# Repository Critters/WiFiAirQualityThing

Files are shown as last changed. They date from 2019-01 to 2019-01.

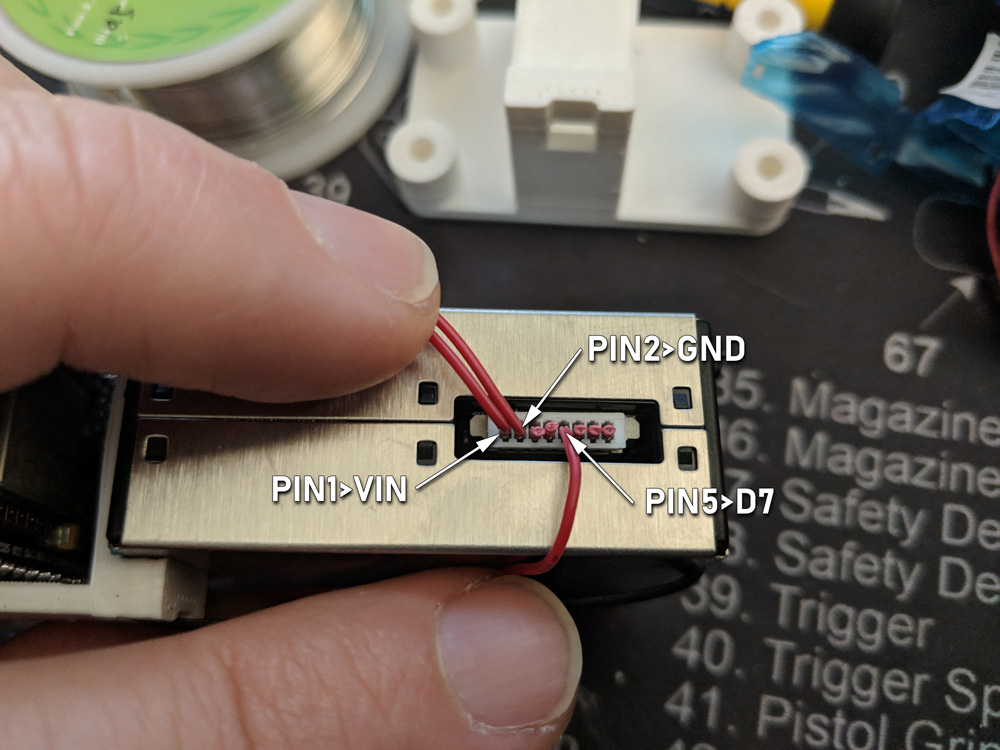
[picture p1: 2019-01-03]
build photos/img-pins.jpg

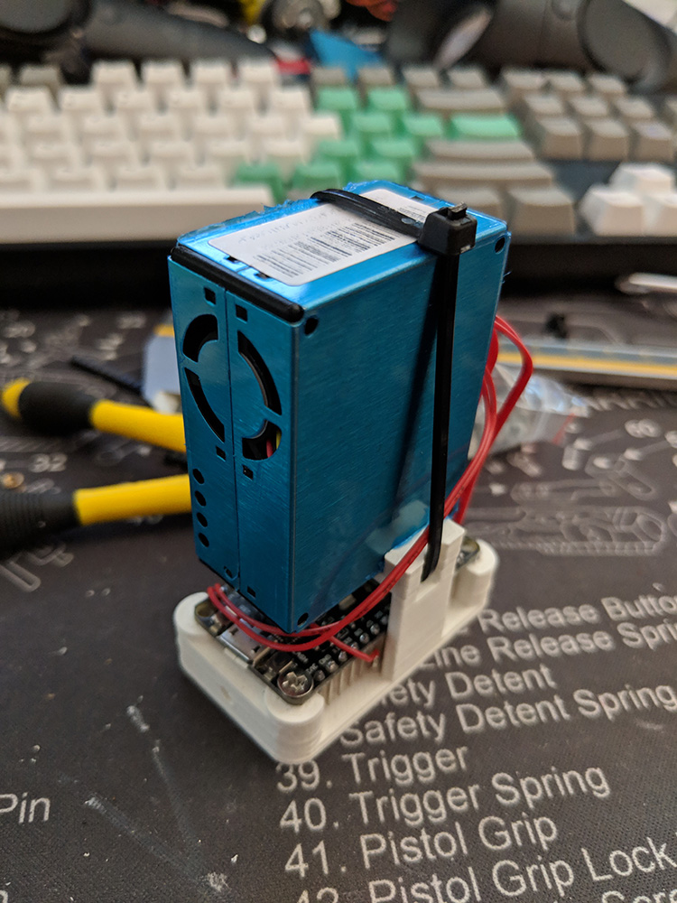
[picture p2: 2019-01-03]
build photos/img-inside.jpg

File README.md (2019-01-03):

When the Camp Fire peaked in California I purchased a handheld air quality sensor and was amazed at how poor the air quality was both indoors and out. It convinced me to get an air filter for my home and identified an issue with the office air filtration. The sensor was loaned to a few friends and was passed around for a while, people found hot spots in their homes and it convinced others to wear masks

It was expensive, and though it had a nice display and measured a bunch of things it didn't store the data or let you extract it, all information was lossed when it was powered down

This project pairs an inexpensive sensor with an equally inexpensive NodeMCU (tiny Arduino board with WiFi) to make a module that will log air quality to Adafruit.IO so you can monitor air quality remotely and have a record. Total build cost is about $20

# FILES
- arduino.ino - the code to upload to the nodeMCU. Replace the strings at the top with your WiFi and Adafruit.IO details and upload using the standard Arduino IDE, google "NodeMCU Arduino" for instructions on adding the board to the IDE
- housing-inside.stl & housing-outside.stl - 3D printable housing

# BOM
- "PMS5003 High Precision Laser Dust Sensor Module" Can be found on eBay for about $16 each from China or double that if you are in a rush and want a US supplier
- "NodeMCU" can also be found on eBay for about $5

## OPTIONAL (if you print the enclosure)
- 5x M3x8 screws
- Zip Tie to fix sensor to housing, though it is a tight fit so not needed if you don't plan to knock it around

# WIRING
Looking at the back of the sensor where the pins are, if you have the pins on the right side of the unit, PIN1 is the left-most pin. See the included "img-pins.jpg" file
- PIN1 - Vin
- PIN2 - Ground
- PIN5 - D7

All other pins are unused. When powered you should hear the fan turn if you hold it to your ear (it is fairly quiet) and with the code uploaded you should see "Started" and data showing up in the ArduinoIDE console

# USAGE
Once you have wired it up and modified the code to include your WiFi and Adafruit.IO details you can just power it up and it will start logging data. If you make more than one just give each one a unique "GROUP_KEY". On your Adafruit.IO page you should see the data appear on your feed, you DON'T need to define the feed names before sending data, they are created automatically

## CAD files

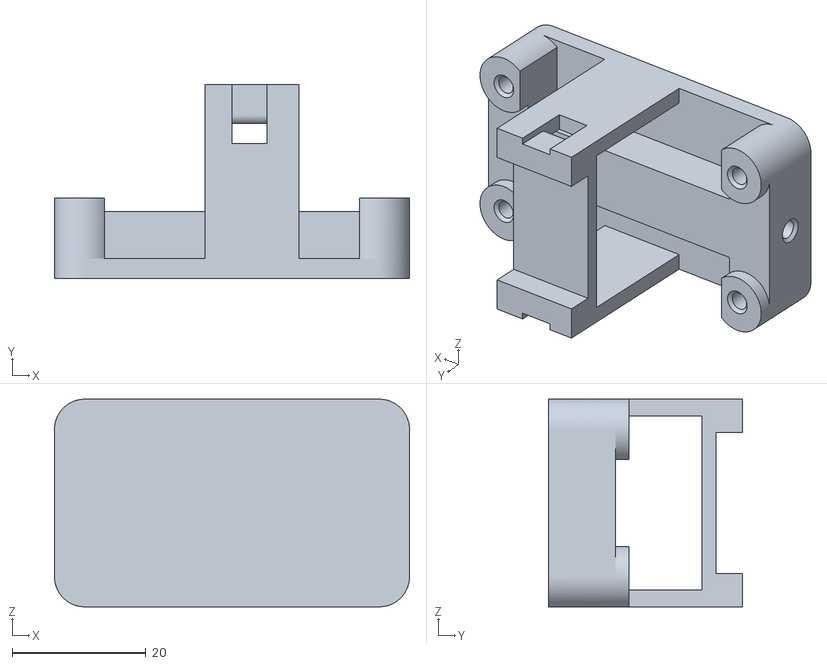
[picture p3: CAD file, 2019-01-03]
3D printable enclosure/Housing-inside.stl
53.0 x 29.0 x 31.0

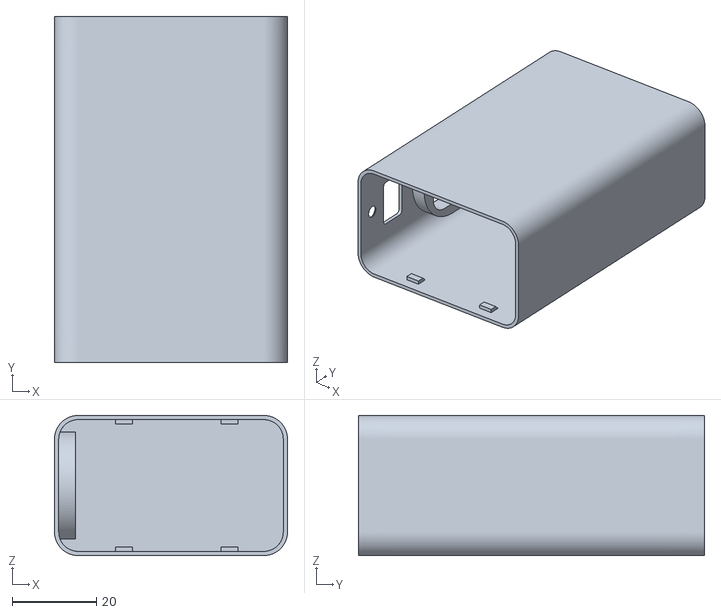
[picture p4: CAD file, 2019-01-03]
3D printable enclosure/Housing-outside.stl
55.2 x 82.0 x 33.2

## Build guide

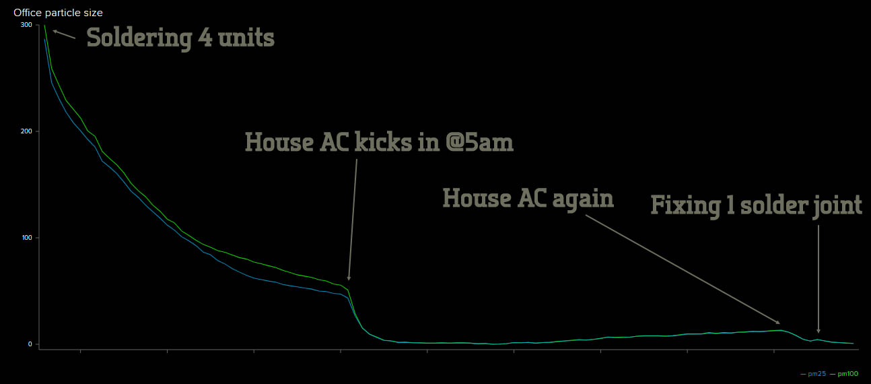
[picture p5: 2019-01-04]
build photos/sample-data.jpg

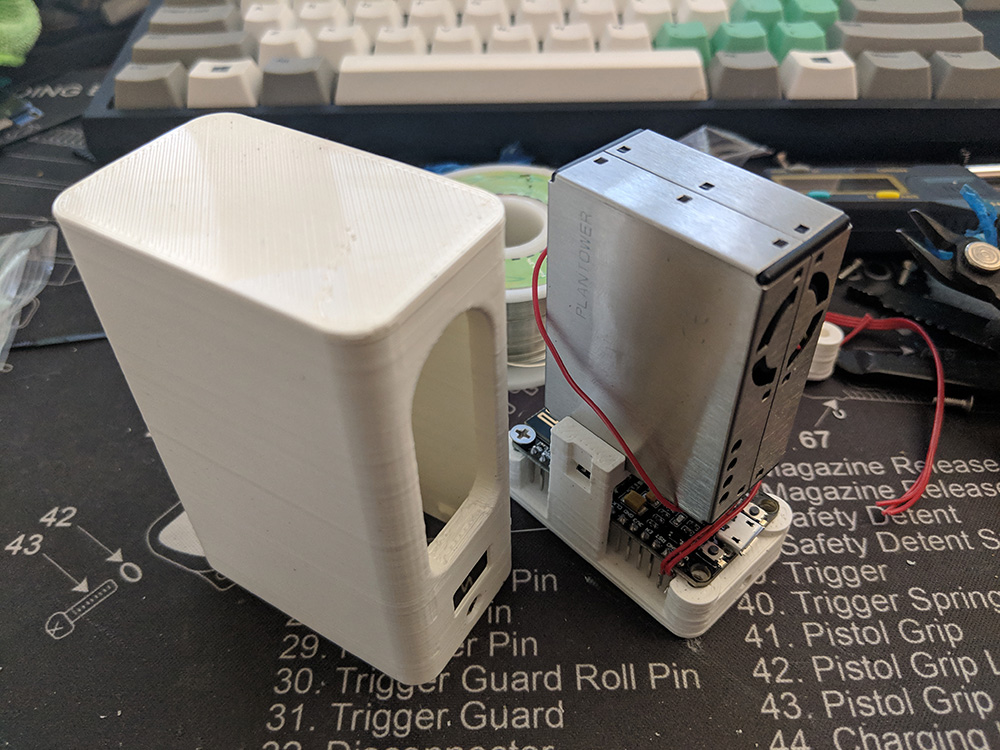
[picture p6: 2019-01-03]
build photos/img-open.jpg

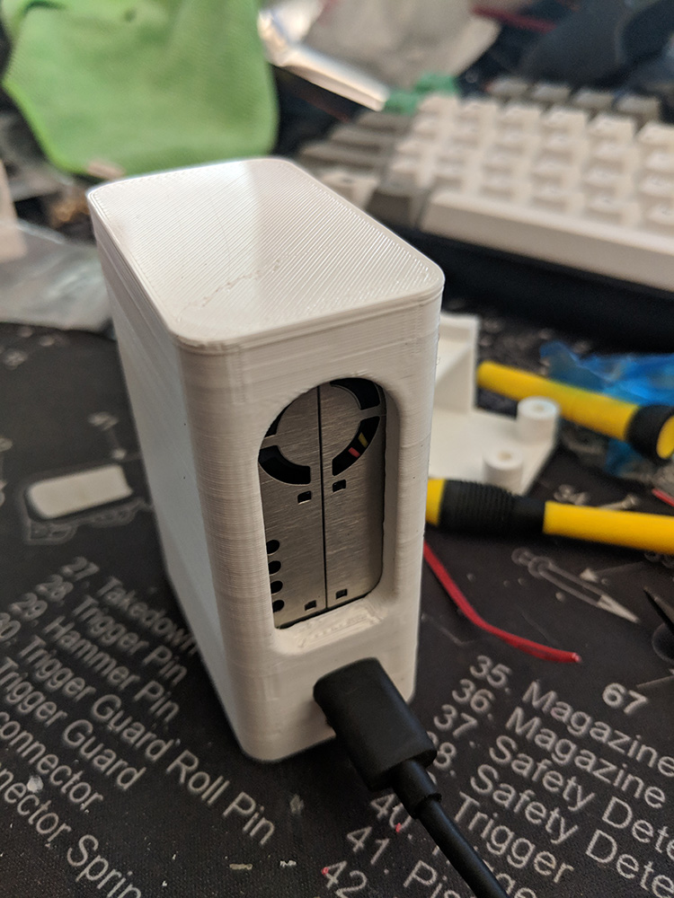
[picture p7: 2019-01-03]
build photos/img-closed.jpg

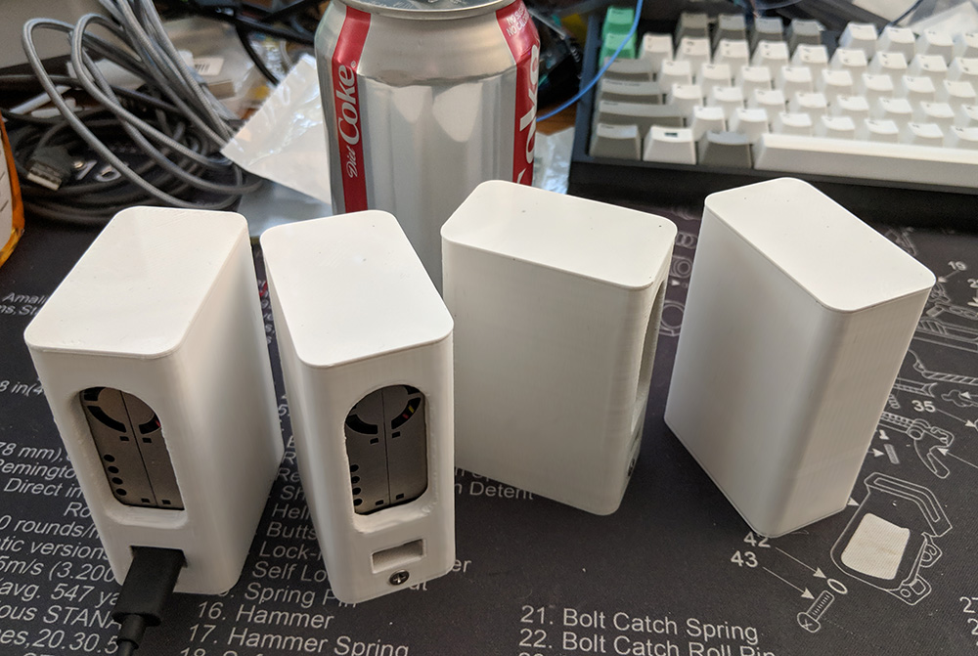
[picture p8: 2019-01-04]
build photos/four.jpg

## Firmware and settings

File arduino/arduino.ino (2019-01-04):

#include "Adafruit_MQTT.h"
#include "Adafruit_MQTT_Client.h"
#include <ESP8266WiFi.h>

// VARIABLES
#define AIO_SERVER      "io.adafruit.com"
#define AIO_SERVERPORT  1883
#define WLAN_SSID       "<<WIFI SSID>>"
#define WLAN_PASS       "<<WIFI PASSWORD>>"
#define IO_USERNAME     "<<ADAFRUIT IO USRNAME>>"
#define IO_KEY          "<<ADAFRUIT IO KEY>>"
#define GROUP_KEY       "<<LOCATION NAME>>"
#define PIN_DATA        7 // RX from pin 5 on the sensor

// The max value that can be sent to the server, prevents your graphs getting ruiened by a huge spike
#define SIZE_VALUE_CAP  500     // For PM2.5 and PM10, the sensor starts to lose accuracy after 500
#define COUNT_VALUE_CAP 50000   // Same, for particle count

/* READ_DELAY: Seconds between readind the sensor
 * if >=60 then sensor will sleep between readings but will wake up 30 seconds before taking a reading (as recommended in the manual)
 * if <60 then the sensor will always be on, you also don't need to wire "PIN_RESET" if you intend to keep it this way */
#define READ_DELAY      60

/* SAMPLE_COUNT: Nnumber of samples to take and average before sending data to Adafruit.IO
 * Therefore, (READ_DELAY * SAMPLE_COUNT) = Time between sending data 
 * NOTE: this is not going to be super accurate, the sensor takes some amount of time to read, the data some amount of time to send, sometimes the sensor data fails the checksum, but it's close enough*/
#define SAMPLE_COUNT    10

// WIFI
WiFiClient client;
Adafruit_MQTT_Client mqtt(&client, AIO_SERVER, AIO_SERVERPORT, IO_USERNAME, IO_KEY);
Adafruit_MQTT_Publish mqttParticles = Adafruit_MQTT_Publish(&mqtt, IO_USERNAME "/feeds/" GROUP_KEY ".particles");
Adafruit_MQTT_Publish mqttPM25 = Adafruit_MQTT_Publish(&mqtt, IO_USERNAME "/feeds/" GROUP_KEY ".pm25");
Adafruit_MQTT_Publish mqttPM100 = Adafruit_MQTT_Publish(&mqtt, IO_USERNAME "/feeds/" GROUP_KEY ".pm100");
void MQTT_connect();

// We store SAMPLE_COUNT values in an array then, once we have filled the array, we average them
int particleArray[SAMPLE_COUNT];  // Particle count
int PM25Array[SAMPLE_COUNT];      // PM2.5 count
int PM100Array[SAMPLE_COUNT];     // PM10 count
int arrayPosition = 0;            // Where in the array we are writing
int particleAverage, PM25Average, PM100Average;   // Used for averaging before sending data to AdafruitIO

// SENSOR
#include <SoftwareSerial.h>
SoftwareSerial pmsSerial(13, PIN_DATA);

// The sensor data is stored here, there is a lot more you could send if you want to expand this beyond particle count and size
// Maybe add a temperature / humidity sensor? That'd be cool
struct pms5003data {
  uint16_t framelen;
  uint16_t pm10_standard, pm25_standard, pm100_standard;
  uint16_t pm10_env, pm25_env, pm100_env;
  uint16_t particles_03um, particles_05um, particles_10um, particles_25um, particles_50um, particles_100um;
  uint16_t unused;
  uint16_t checksum;
};
struct pms5003data data;
 
void setup() {
  Serial.begin(115200);
  pmsSerial.begin(9600);
  
  // WIFI
  Serial.print("Connecting to ");
  Serial.println(WLAN_SSID);

  WiFi.begin(WLAN_SSID, WLAN_PASS);
  while (WiFi.status() != WL_CONNECTED) {
    delay(500);
    Serial.print(".");
  }
  Serial.println();

  Serial.println("WiFi connected");
  Serial.print("IP address: "); Serial.println(WiFi.localIP());
  MQTT_connect();
  
  Serial.print("\nSampling every "); Serial.print(READ_DELAY); Serial.print(" seconds, and send data every "); Serial.print((SAMPLE_COUNT*READ_DELAY)/60); Serial.print(" minutes (averaging "); Serial.print(SAMPLE_COUNT); Serial.println(" values)");
}


void loop() {
  if(readPMSdata(&pmsSerial)) {
      Serial.print(arrayPosition+1); Serial.print("/"); Serial.print(SAMPLE_COUNT); Serial.print(": ");
      Serial.print("PM2.5: "); Serial.print(data.pm25_env); Serial.print(", "); 
      Serial.print("PM10: "); Serial.print(data.pm100_env); Serial.print(", "); 
      Serial.print("Particles: "); Serial.print(data.particles_03um); 
      Serial.print("\n");

      particleArray[arrayPosition] = data.particles_03um;
      PM25Array[arrayPosition] = data.pm25_env;
      PM100Array[arrayPosition] = data.pm100_env;
      arrayPosition++;
      if(arrayPosition == SAMPLE_COUNT){
          particleAverage = 0;
          PM25Average = 0;
          PM100Average = 0;
          for(int i = 0; i<SAMPLE_COUNT; i++){
              particleAverage += particleArray[i];
              PM25Average += PM25Array[i];
              PM100Average += PM100Array[i];
          }
          MQTT_connect();
          mqttParticles.publish(min(COUNT_VALUE_CAP, particleAverage/SAMPLE_COUNT));
          mqttPM25.publish(min(SIZE_VALUE_CAP, PM25Average/SAMPLE_COUNT));
          mqttPM100.publish(min(SIZE_VALUE_CAP, PM100Average/SAMPLE_COUNT));
          
          arrayPosition = 0;

          Serial.print("SENT AVERAGE: ");
          Serial.print(PM25Average/SAMPLE_COUNT); Serial.print(","); 
          Serial.print(PM100Average/SAMPLE_COUNT); Serial.print(","); 
          Serial.print(particleAverage/SAMPLE_COUNT); 
          Serial.print("\n");
      }

      delay(READ_DELAY*1000);
  }
}
 
boolean readPMSdata(Stream *s) {
  if (! s->available()) {
    return false;
  }
  
  // Read a byte at a time until we get to the special '0x42' start-byte
  if (s->peek() != 0x42) {
    s->read();
    return false;
  }
 
  // Now read all 32 bytes
  if (s->available() < 32) {
    return false;
  }
    
  uint8_t buffer[32];    
  uint16_t sum = 0;
  s->readBytes(buffer, 32);
 
  // get checksum ready
  for (uint8_t i=0; i<30; i++) {
    sum += buffer[i];
  }
  
  
  // The data comes in endian'd, this solves it so it works on all platforms
  uint16_t buffer_u16[15];
  for (uint8_t i=0; i<15; i++) {
    buffer_u16[i] = buffer[2 + i*2 + 1];
    buffer_u16[i] += (buffer[2 + i*2] << 8);
  }
 
  // put it into a nice struct :)
  memcpy((void *)&data, (void *)buffer_u16, 30);
 
  if (sum != data.checksum) {
    //Serial.println("Checksum failure");
    return false;
  }
  // success!
  return true;
}

void MQTT_connect() {
  int8_t ret;

  // Stop if already connected.
  if (mqtt.connected()) {
    return;
  }

  Serial.print("Connecting to MQTT... ");

  uint8_t retries = 3;
  while ((ret = mqtt.connect()) != 0) { // connect will return 0 for connected
       Serial.println(mqtt.connectErrorString(ret));
       Serial.println("Retrying MQTT connection in 5 seconds...");
       mqtt.disconnect();
       delay(5000);  // wait 5 seconds
       retries--;
       if (retries == 0) {
         // basically die and wait for WDT to reset me
         while (1);
       }
  }
  Serial.println("MQTT Connected!");
}

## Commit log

2019-01-03 Initial Upload
    [Housing-Inside.stl, Housing-outside.stl]
2019-01-04 Tidying up
    [Housing-inside.stl, Housing-outside.stl]
2019-01-04 Code update
    Added comments, removed hardcoding of pins and made sample count a variable the user can set
2019-01-04 A couple of extra images
